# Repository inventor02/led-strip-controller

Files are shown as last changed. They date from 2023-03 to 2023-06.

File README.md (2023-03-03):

# led-strip-controller

The LED Strip Controller is a RP2040 (Pi Pico) based controller for a 12V DC LED strip we had lying around. Instead of
spending £20 on a cheap controller, why not spend much more (and countless hours) on making our own absurdly overengineered
one!?

## Firmware

The firmware, located in `firmware` is WIP.

## Hardware

### PCB

The entire controller is based around one PCB available in the `hardware/board` directory. It is designed using KiCad.

### Box

There is a box that can be 3D printed to fit the PCB and its components well. It is in the `hardware/box` directory, and
was designed using FreeCAD.

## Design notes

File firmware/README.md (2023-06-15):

# led-strip-controller firmware

This is firmware for an RP2040 microcontroller from Raspberry Pi. We use a Pi Pico soldered directly onto the PCB, but theoretically you could use any other RP2040-based board (or even just an RP2040 itself, if you take care of the voltage).

## Resources

- [https://www.techdesign.be/projects/011/011_waves.htm] is a useful page detailing timing requirements for the Samsung IR protocol - Samsung also have an application note which if you're good at looking you can find, and the timings there match too. In the real world the tolerances are much higher anyway.

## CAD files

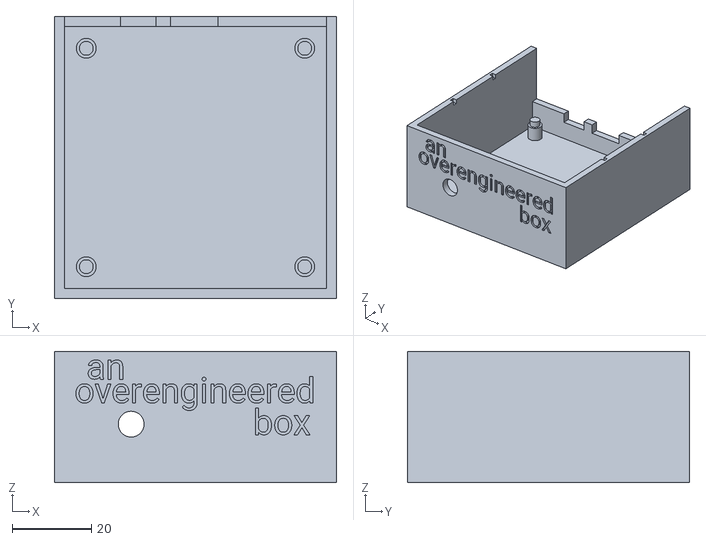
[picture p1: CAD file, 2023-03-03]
hardware/board/release/box/v5_base.stl
71.0 x 71.0 x 33.0

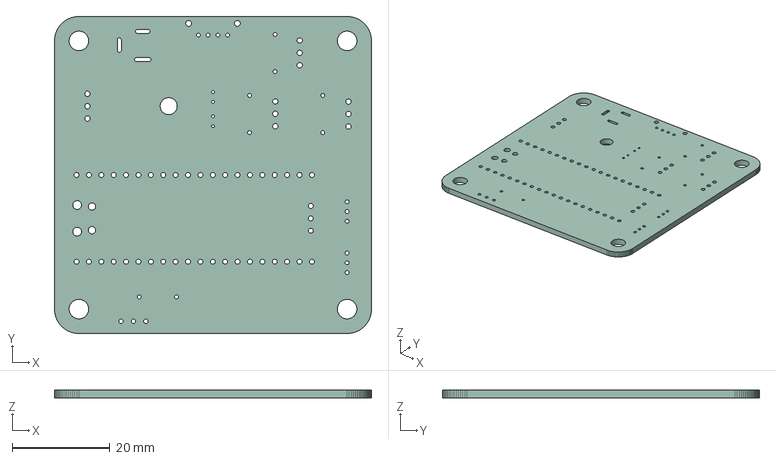
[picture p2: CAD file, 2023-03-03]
hardware/board/release/led_strip_controller.step
65.0 x 65.0 x 1.60 mm

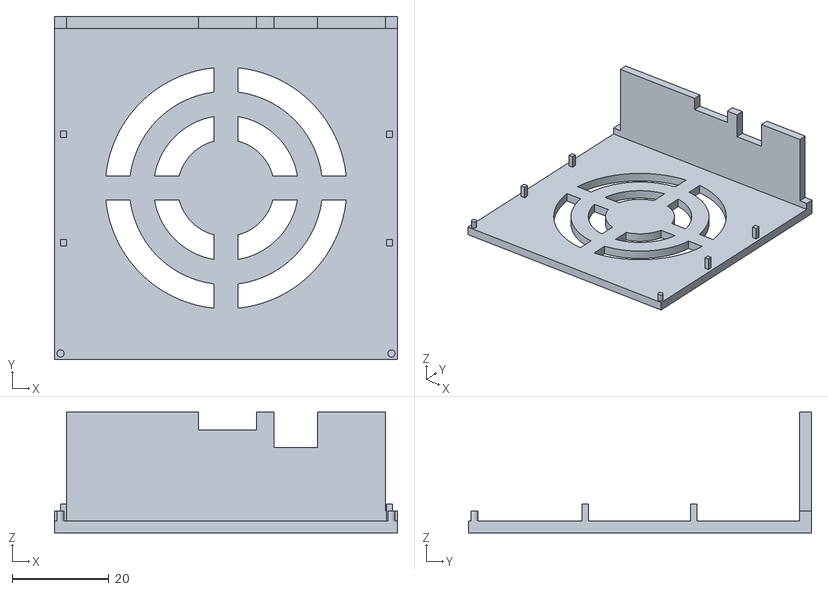
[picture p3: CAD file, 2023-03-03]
hardware/board/release/box/v5_top.stl
71.0 x 71.0 x 25.0

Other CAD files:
hardware/box/boxv5.FCStd

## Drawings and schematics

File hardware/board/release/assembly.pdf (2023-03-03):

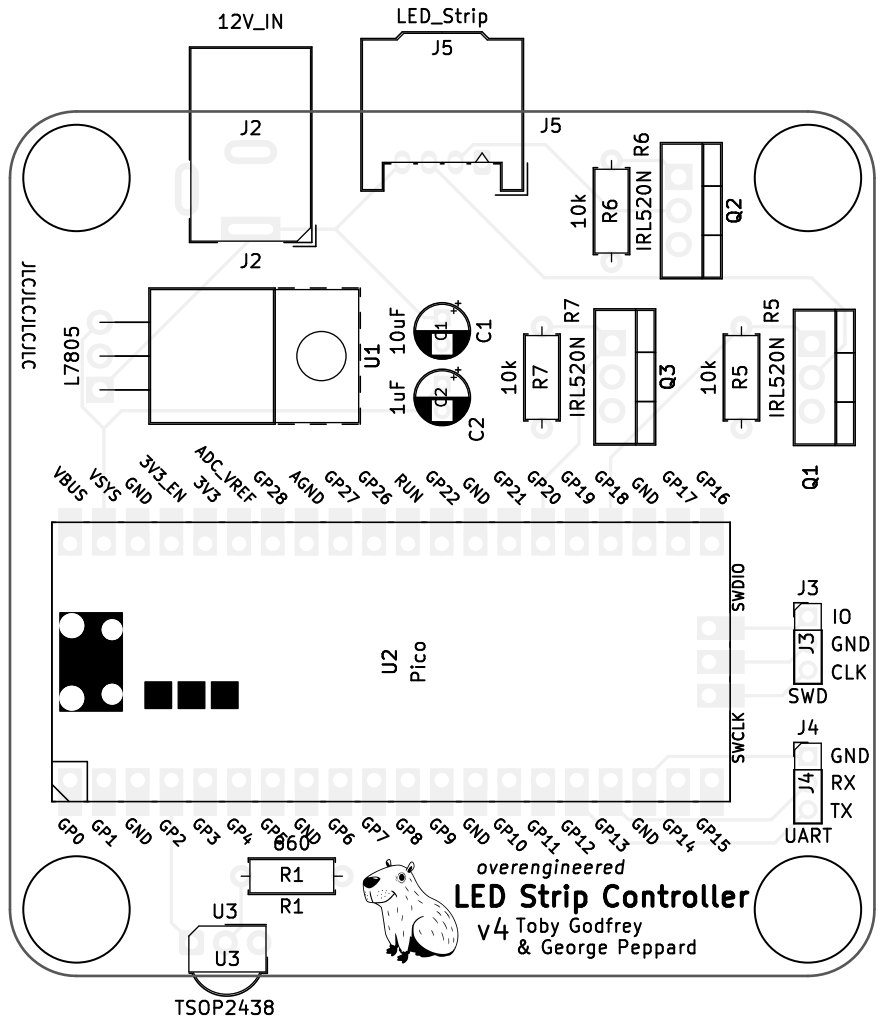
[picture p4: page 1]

Toby Godfrey & George Peppard

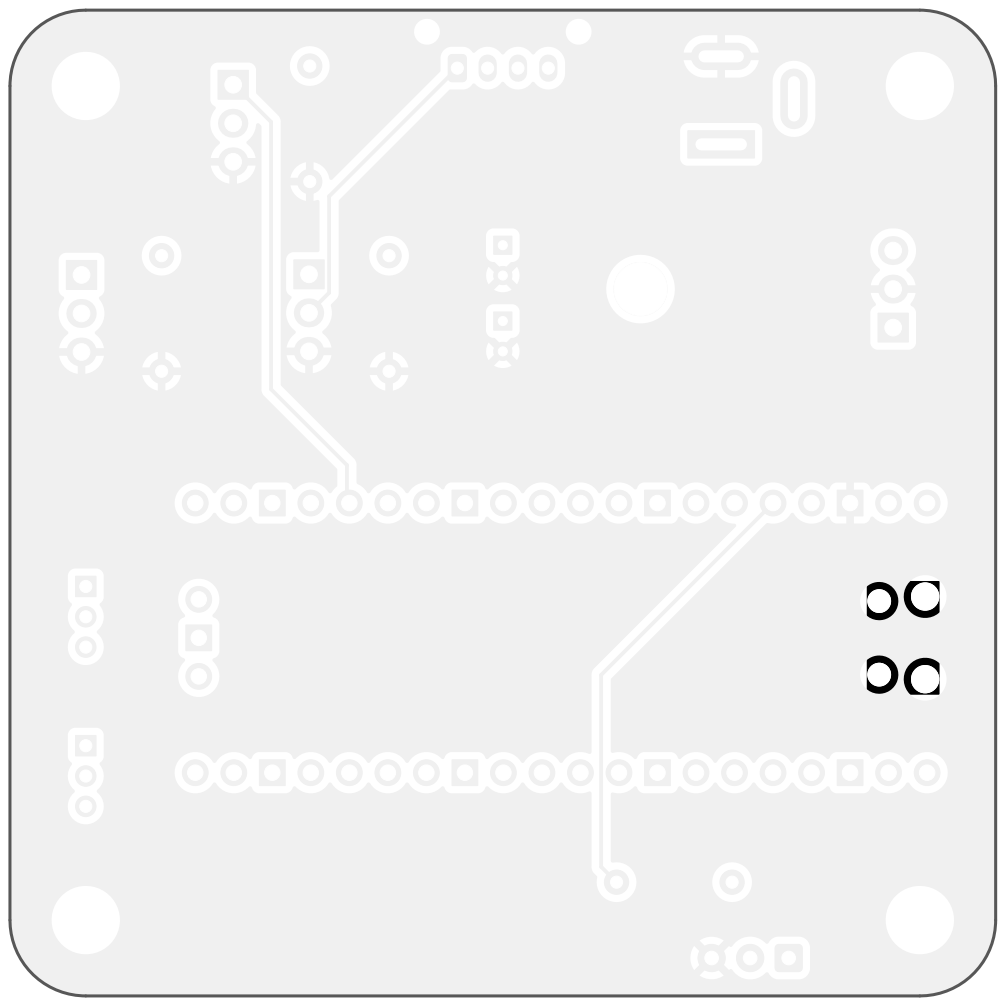
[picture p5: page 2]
D Date: 2023-03-02 KiCad; kicad; 7.0.0-1.fc37 Size: A4; Rev: 4; Id: 1/1 Title: LED Strip Controller File: led_strip_controller.kicad_pcb Sheet: Toby Godfrey & George; Peppard

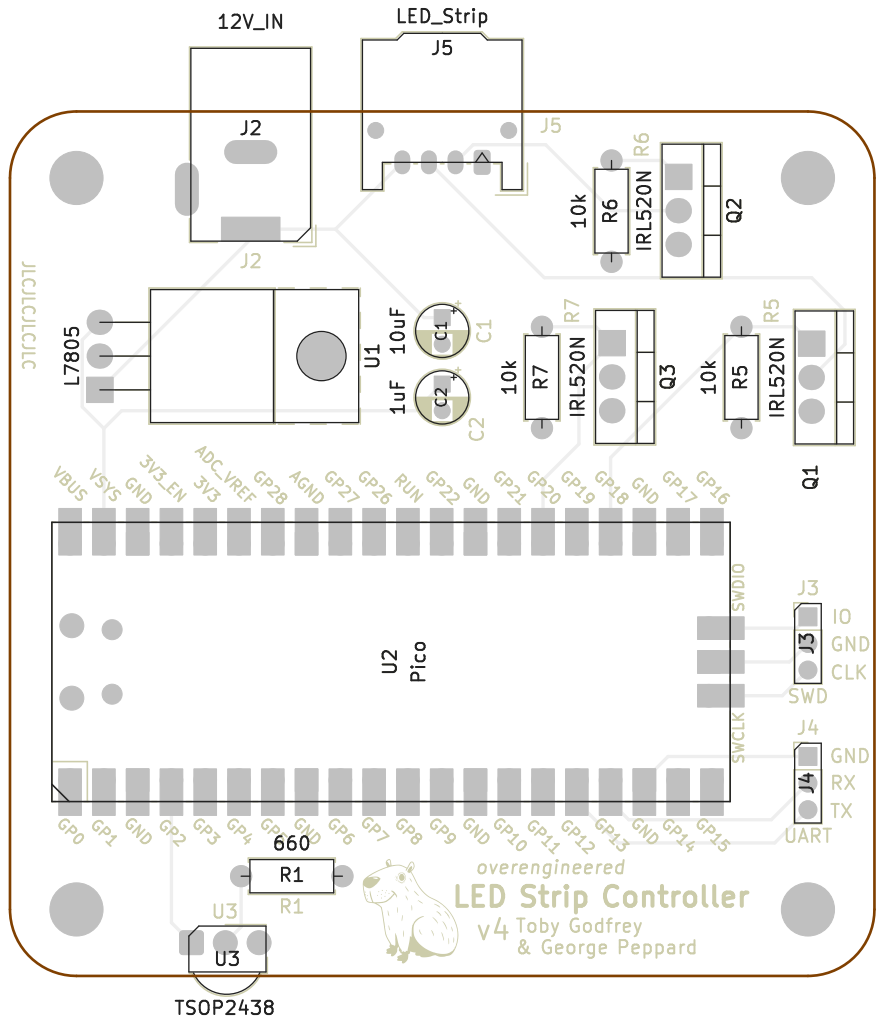
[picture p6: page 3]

Toby Godfrey & George Peppard

Id: 1/1 Title: LED Strip Controller File: led_strip_controller.kicad_pcb Sheet: Toby Godfrey & George Peppard

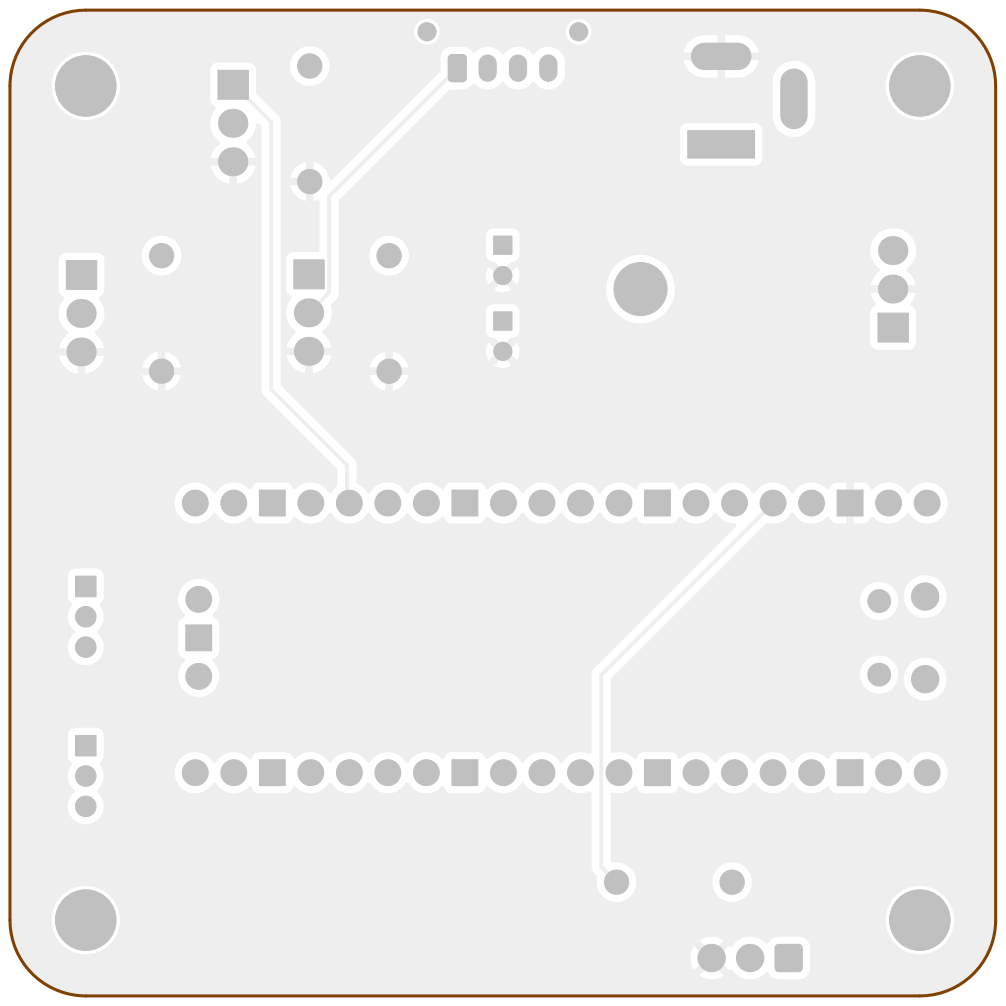
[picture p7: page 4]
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

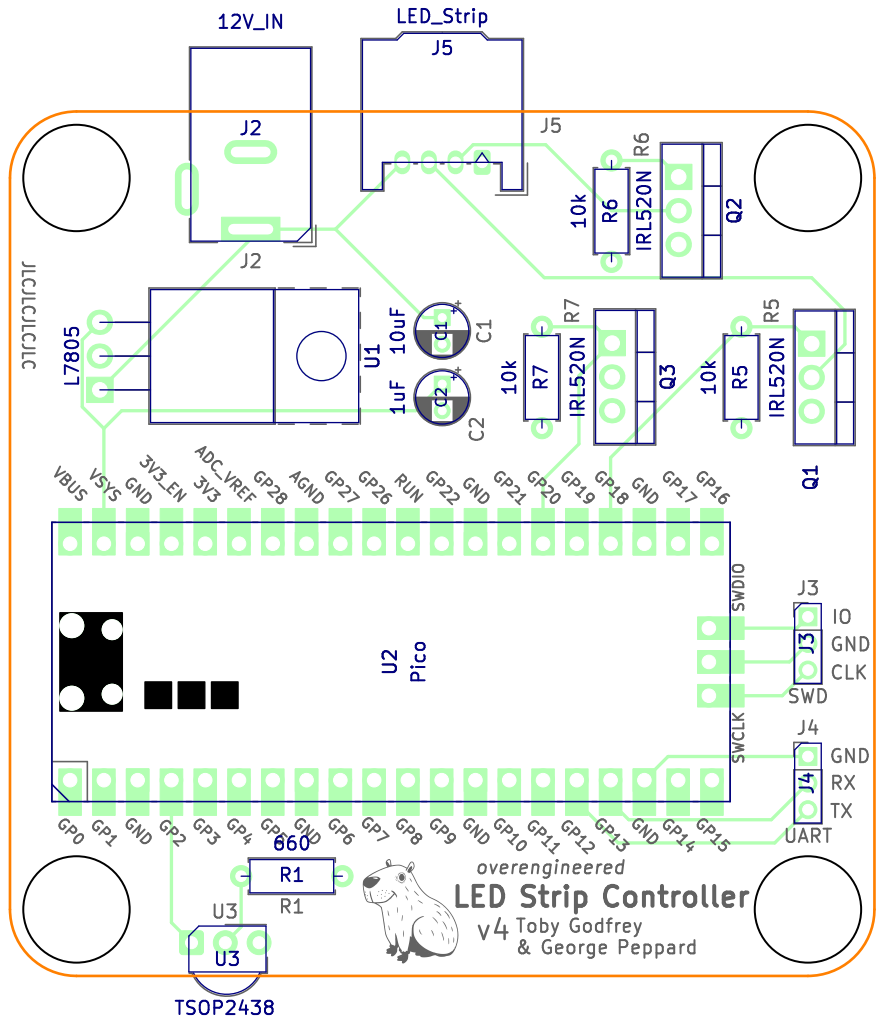
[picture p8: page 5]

Toby Godfrey & George Peppard

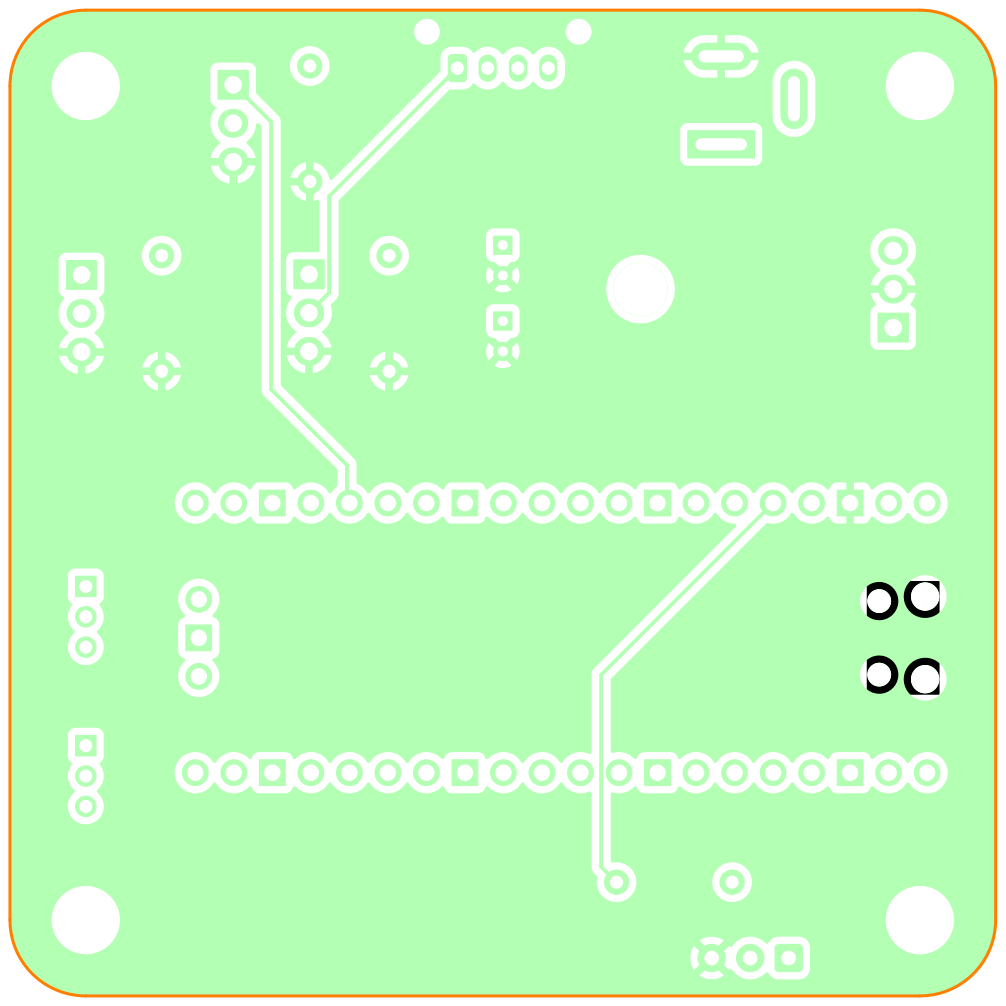
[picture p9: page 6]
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

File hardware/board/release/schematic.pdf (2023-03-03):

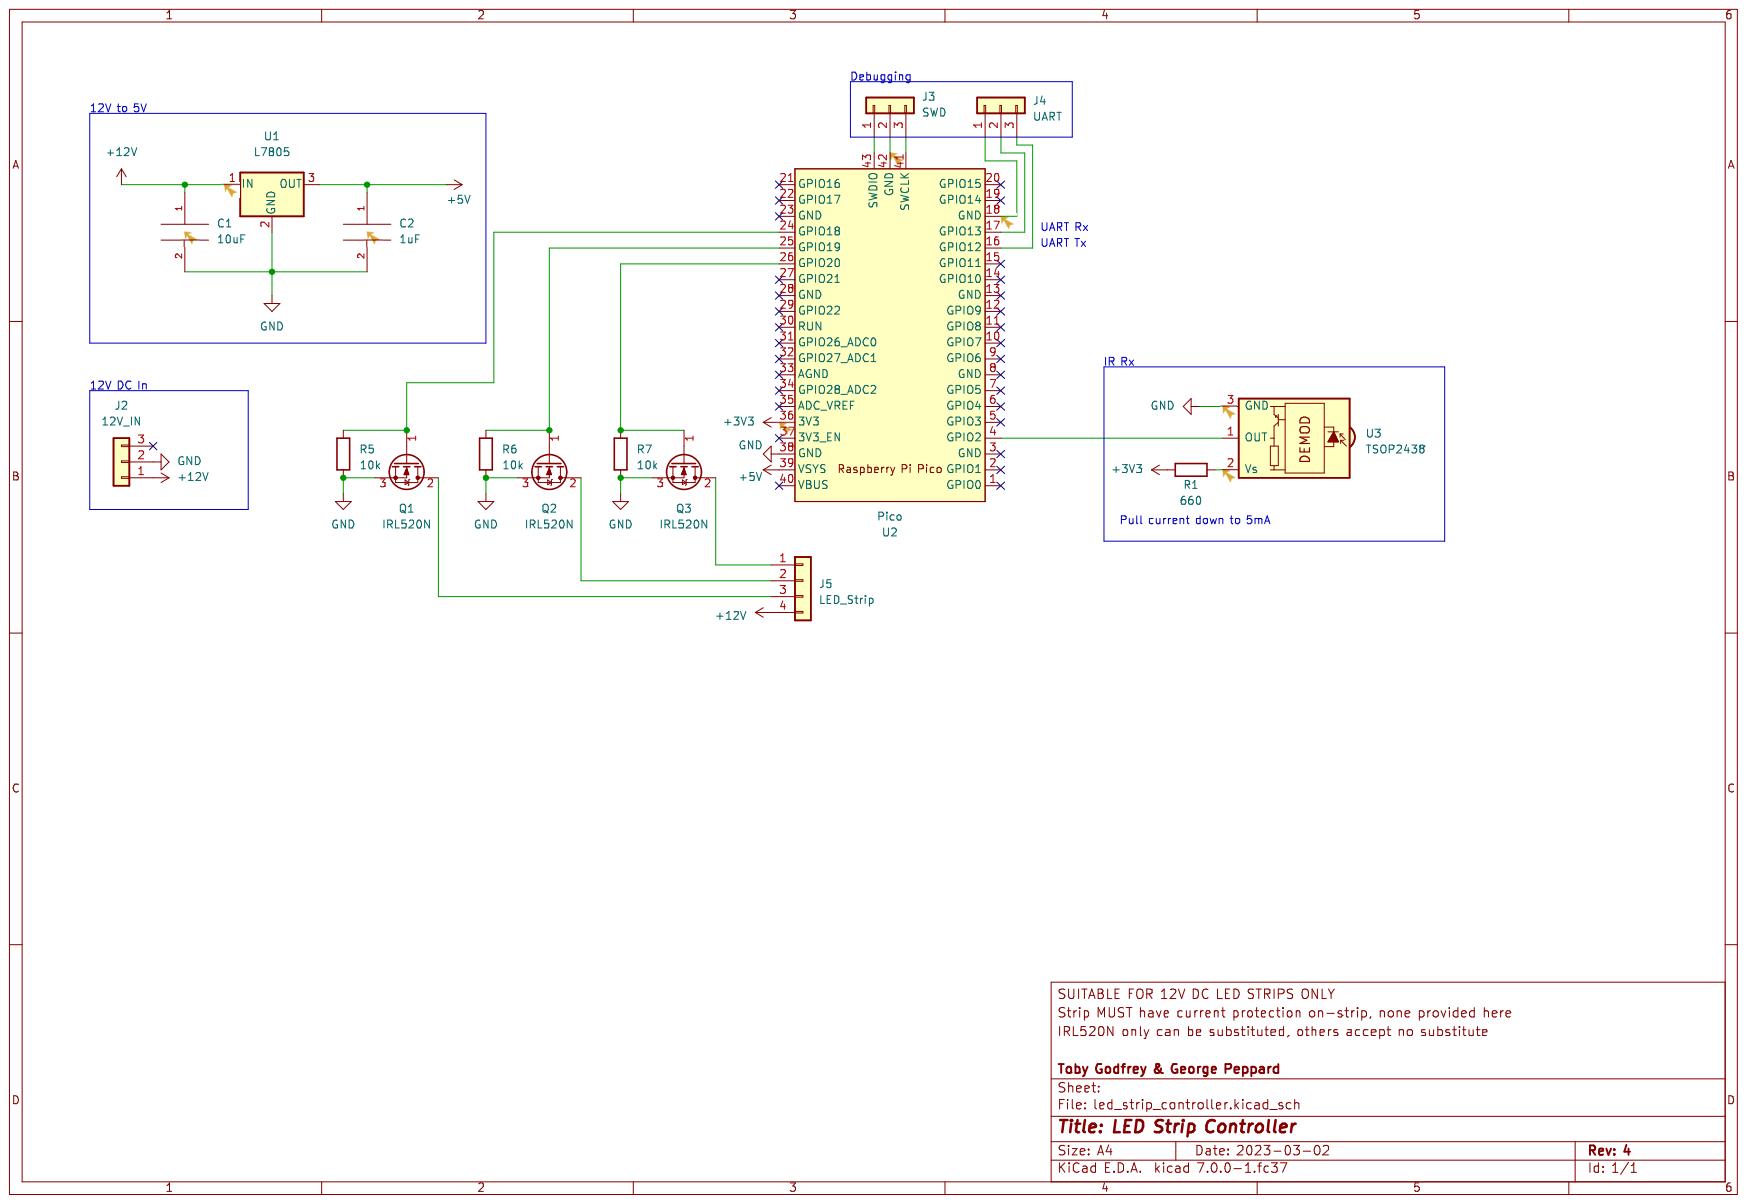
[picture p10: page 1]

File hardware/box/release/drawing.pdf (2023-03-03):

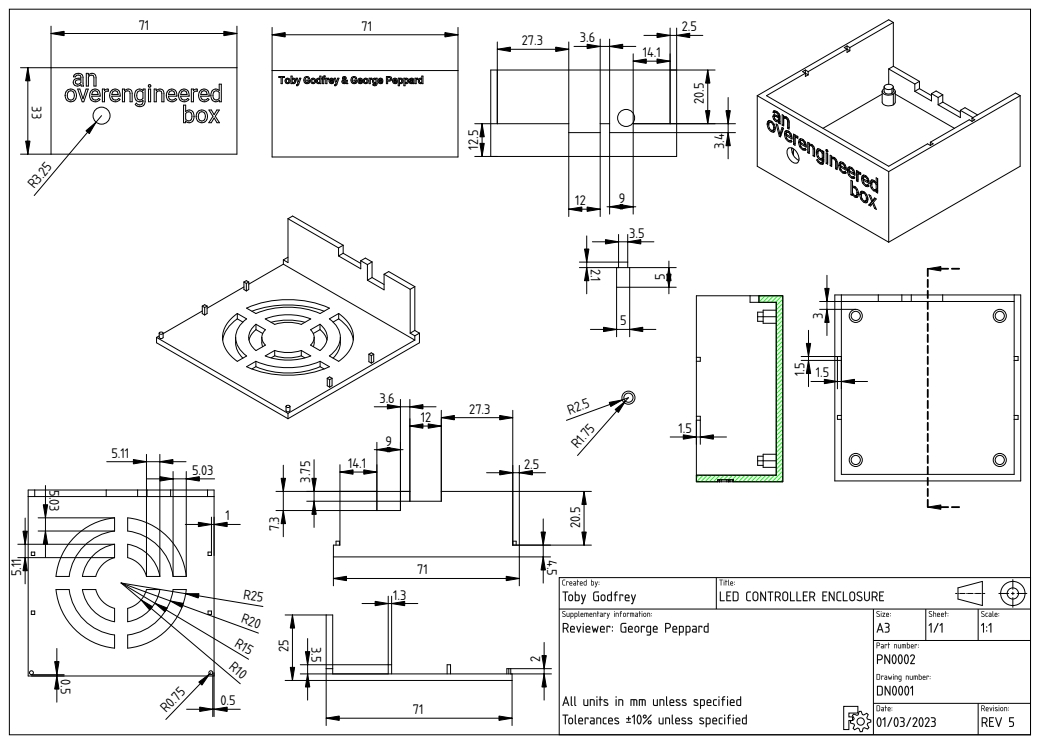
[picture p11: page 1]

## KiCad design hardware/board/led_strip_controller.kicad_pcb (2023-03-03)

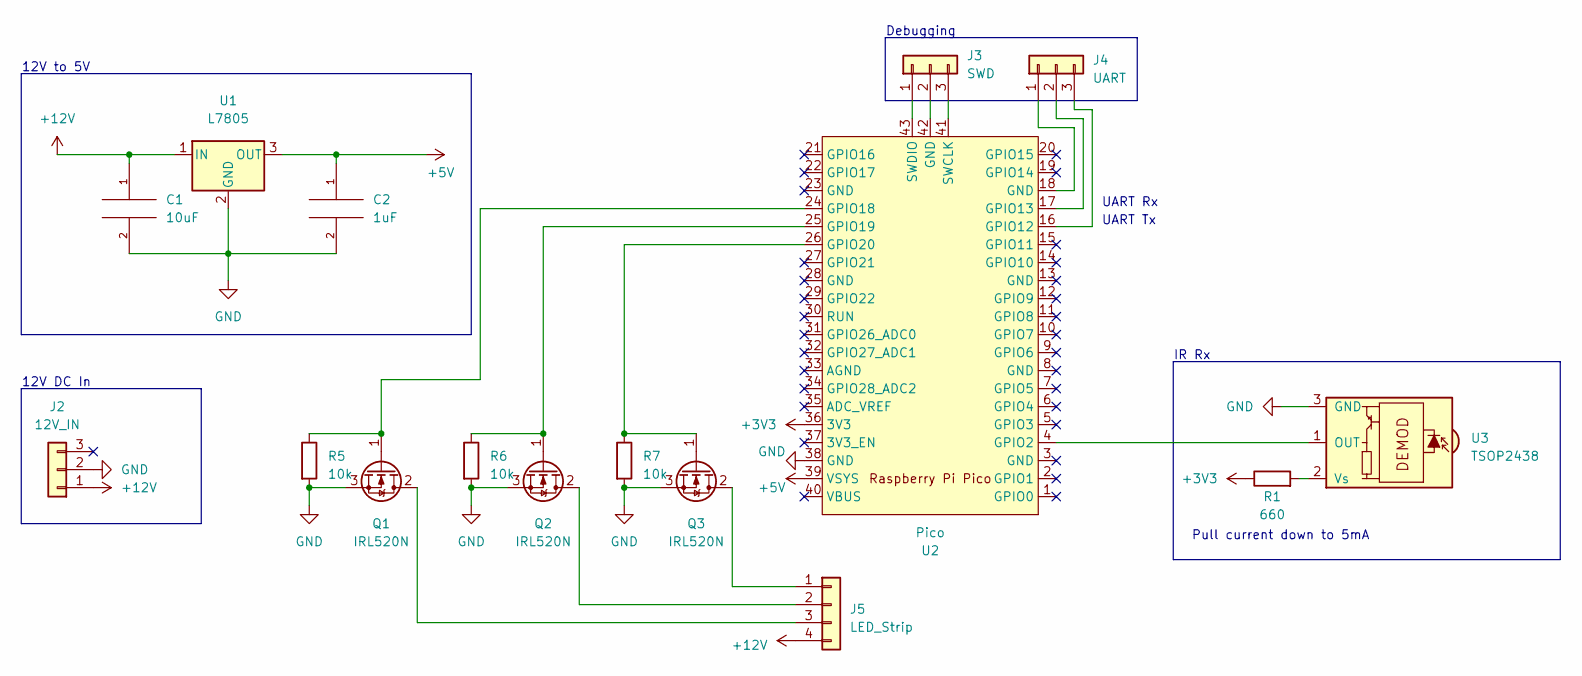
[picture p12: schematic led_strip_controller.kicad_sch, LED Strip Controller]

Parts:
C1: 10uF; CP_Radial_D4.0mm_P2.00mm
C2: 1uF; CP_Radial_D4.0mm_P2.00mm
J2: 12V_IN; BarrelJack_Wuerth_6941xx301002
J3: SWD; PinHeader_1x03_P2.00mm_Vertical
J4: UART; PinHeader_1x03_P2.00mm_Vertical
J5: LED_Strip; Molex_MicroClasp_55935-0410_1x04_P2.00mm_Horizontal
Q1, Q2, Q3: IRL520N; TO-220-3_Vertical
R1: 660; R_Axial_DIN0207_L6.3mm_D2.5mm_P7.62mm_Horizontal
R5, R6, R7: 10k; R_Axial_DIN0207_L6.3mm_D2.5mm_P7.62mm_Horizontal
U1: L7805; TO-220-3_Horizontal_TabUp
U2: Pico; RPi_Pico_SMD_TH
U3: TSOP2438; Vishay_MOLD-3Pin

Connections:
+3V3: R1.1, U2.36 (3V3)
+5V: C2.1, U1.3 (OUT), U2.39 (VSYS)
+12V: C1.1, J2.1, J5.4, U1.1 (IN)
GND: C1.2, C2.2, J2.2, Q1.3 (S), Q2.3 (S), Q3.3 (S), R5.2, R6.2, R7.2, U1.2 (GND), U2.38 (GND), U3.3 (GND)
unnamed: J3.1, U2.43 (SWDIO)
unnamed: J3.2, U2.42 (GND)
unnamed: J3.3, U2.41 (SWCLK)
unnamed: J4.1, U2.18 (GND)
unnamed: J4.2, U2.17 (GPIO13)
unnamed: J4.3, U2.16 (GPIO12)
unnamed: J5.1, Q3.2 (D)
unnamed: J5.2, Q2.2 (D)
unnamed: J5.3, Q1.2 (D)
unnamed: Q1.1 (G), R5.1, U2.24 (GPIO18)
unnamed: Q2.1 (G), R6.1, U2.25 (GPIO19)
unnamed: Q3.1 (G), R7.1, U2.26 (GPIO20)
unnamed: U2.4 (GPIO2), U3.1 (OUT)
unnamed: R1.2, U3.2 (Vs)

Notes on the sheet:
UART Rx
Pull current down to 5mA
Debugging
UART Tx
12V DC In
12V to 5V
IR Rx

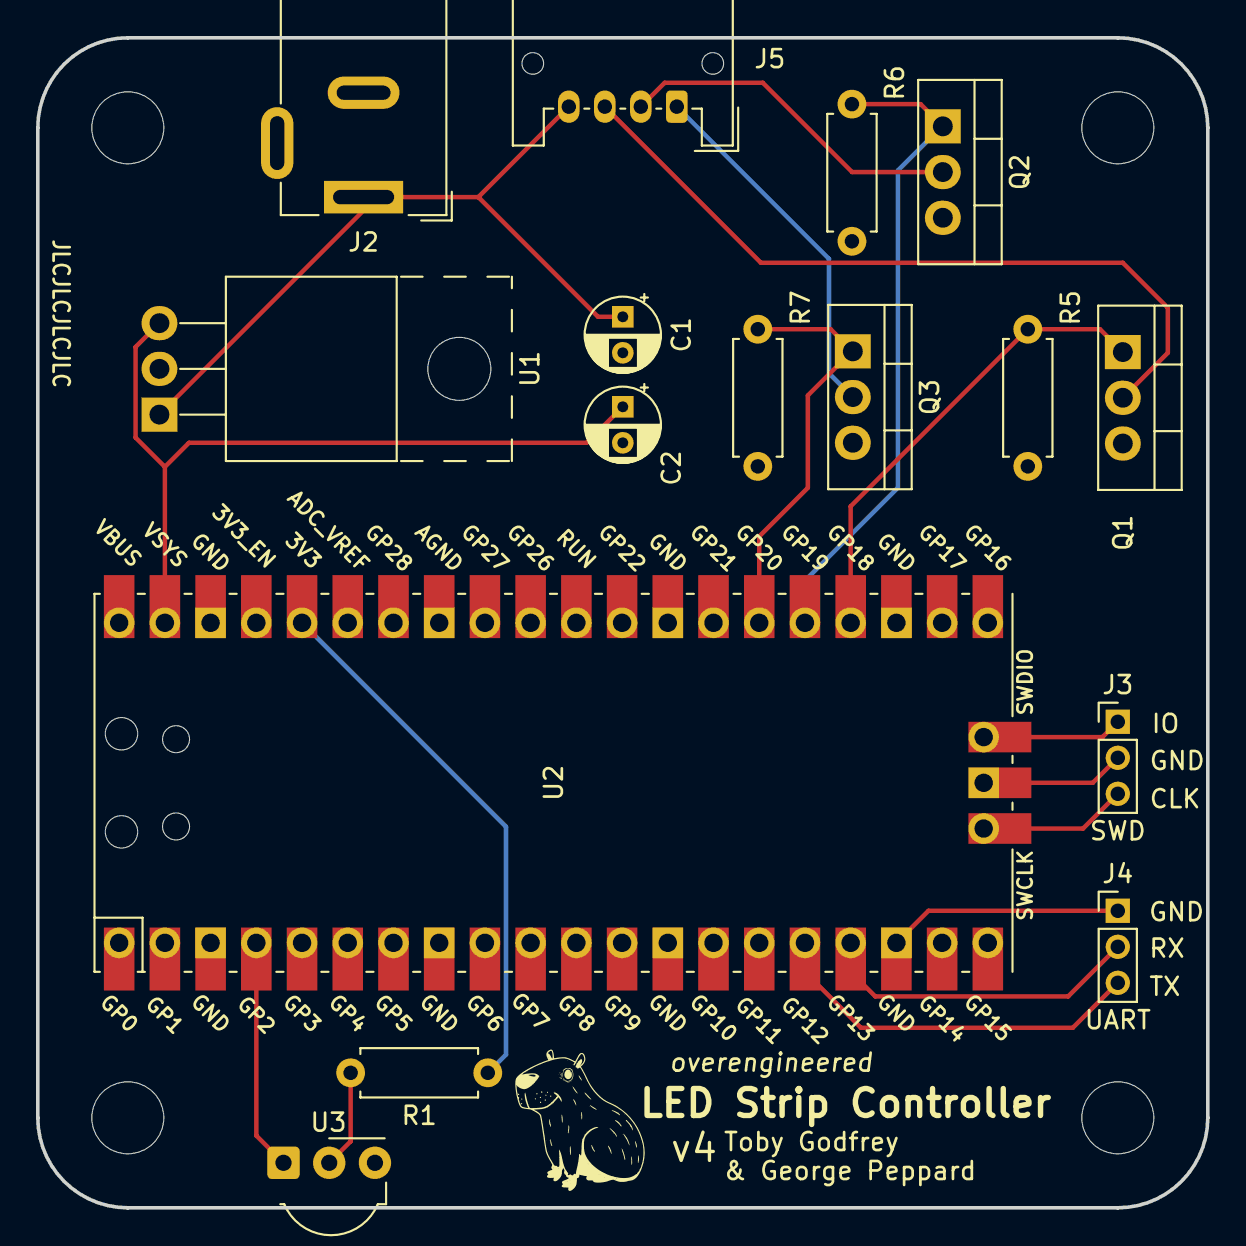
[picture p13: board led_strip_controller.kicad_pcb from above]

Board: 2 copper layers, 65.0 x 65.0 mm, 16 parts (0 on the bottom side), 18 nets.

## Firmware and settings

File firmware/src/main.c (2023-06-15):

#include <stdio.h>
#include <time.h>
#include <math.h>

#include "pico/stdlib.h"
#include "hardware/gpio.h"
#include "hardware/sync.h"
#include "hardware/timer.h"
#include "hardware/pwm.h"
#include "hardware/pio.h"

#include "defs.h"
#include "ir_rx.pio.h"

// % of full power
double red_val = 0;
double green_val = 0;
double blue_val = 0;

bool lights_on = false;

static PIO pio = pio0;
static uint pio_sm;

void self_test() {
  // TODO
}

void set_pwm(double red, double green, double blue) {
  uint red_pwm = floor(red * PWM_WRAP);
  uint green_pwm = floor(green * PWM_WRAP);
  uint blue_pwm = floor(blue * PWM_WRAP);

  pwm_set_gpio_level(PIN_PWM_RED, red_pwm);
  pwm_set_gpio_level(PIN_PWM_GREEN, green_pwm);
  pwm_set_gpio_level(PIN_PWM_BLUE, blue_pwm);
}

void write_light_stored_vals() {}
void write_light_custom_vals(double red, double green, double blue) {}

void button_on_off_toggle() {
  if(!lights_on){
    // Turn on
    lights_on = true;
    // Write the stored values to the lights
    write_light_stored_vals();
  } else {
    lights_on = false;
    // Don't update the values, just write 0 to all of the lights 
    write_light_custom_vals(0, 0, 0);
  }
}

void update_val(double* val) {
  *val += 0.1;
  if(*val > 1) *val -= 1;
}

void ir_isr(uint gpio, uint32_t events) {
  uint32_t state = save_and_disable_interrupts();
  // GPIO_GET 0 - low, !=0 high

  // Check start bit - 4.5ms high, 4.5ms low => 4.5ms low, 4.5ms high
  bool was_low = true;
  bool was_high = true;
  busy_wait_ms(2);
  if (gpio_get(PIN_IR) != 0) was_low = false;
  busy_wait_us(4500);
  // Should switch to high now after ~0.5ms
  // Now 1.5ms into high band
  if (gpio_get(PIN_IR) == 0) was_high = false;

  // Now at ~6.5ms
  busy_wait_us(2000);

  uint8_t bits[32];
  uint32_t code = 0;

  if (was_low && was_high) { // Start bit found
    for (uint8_t i = 0; i < 32; i++) {
      busy_wait_us(560); // Wait until start of second pulse
      // 1.69ms high for 1, 0.56ms high for 0
      
      busy_wait_us(560);
      if (gpio_get(PIN_IR) != 0) {
        code += 2^i;
        busy_wait_us(1130);
        printf("high\n");
      } // Still high
      else continue;
    }
  } else {
    restore_interrupts(0);
    return;
  }


  // Store Data
  switch (code) {
    case POWER_CODE:
      button_on_off_toggle();
      break;
    case RED_CODE:
      update_val(&red_val);
      break;
    case GREEN_CODE:
      update_val(&green_val);
      break;
    case BLUE_CODE:
      update_val(&blue_val);
      break;
    
    default:
      write_light_custom_vals(1, 1, 1);
      break;
  }

  printf("%d\n", code);

  write_light_stored_vals();
  restore_interrupts(0);
}

void init() {
  // setup LED
  gpio_init(PIN_LED);
  gpio_set_dir(PIN_LED, GPIO_OUT);
  gpio_put(PIN_LED, 1);

  // setup UART
  stdio_uart_init_full(uart0, 115200, PIN_UART_TX, PIN_UART_RX);
  printf("Hello; LED Strip Controller v%s\n\n", VERSION);

  // set pins for PWM
  gpio_set_function(PIN_PWM_RED, GPIO_FUNC_PWM);
  gpio_set_function(PIN_PWM_GREEN, GPIO_FUNC_PWM);
  gpio_set_function(PIN_PWM_BLUE, GPIO_FUNC_PWM);

  uint pwm_red_slice = pwm_gpio_to_slice_num(PIN_PWM_RED);
  uint pwm_green_slice = pwm_gpio_to_slice_num(PIN_PWM_GREEN);
  uint pwm_blue_slice = pwm_gpio_to_slice_num(PIN_PWM_BLUE);

  pwm_set_wrap(pwm_red_slice, PWM_WRAP);
  pwm_set_wrap(pwm_green_slice, PWM_WRAP);
  pwm_set_wrap(pwm_blue_slice, PWM_WRAP);

  pwm_set_gpio_level(PIN_PWM_RED, 0);
  pwm_set_gpio_level(PIN_PWM_GREEN, 0);
  pwm_set_gpio_level(PIN_PWM_BLUE, 0);

  pwm_set_enabled(pwm_red_slice, true);
  pwm_set_enabled(pwm_green_slice, true);
  pwm_set_enabled(pwm_blue_slice, true);

  pio_sm = pio_claim_unused_sm(pio, true);
  uint offset = pio_add_program(pio, &ir_rx_program);
  ir_rx_program_init(pio, pio_sm, offset, PIN_IR);

  printf("Initialisation complete\n");
}

int main() {
  init();
  self_test();

  for (;;) {
    uint32_t rx = pio_sm_get_blocking(pio, pio_sm);
    printf("received: %x\n", rx);
  }
}

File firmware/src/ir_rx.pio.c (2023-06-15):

#include "ir_rx.pio.h"

#include "pico/stdlib.h"
#include "hardware/pio.h"
#include "hardware/clocks.h"

void ir_rx_program_init(PIO pio, uint sm, uint offset, uint gpio)
{
    // get the default config for this program
    pio_sm_config config = ir_rx_program_get_default_config(offset);

    // set up our pins
    pio_gpio_init(pio, gpio);
    gpio_pull_up(gpio);
    pio_sm_set_consecutive_pindirs(pio, sm, gpio, 1, false);
    sm_config_set_in_pins(&config, gpio);
    sm_config_set_jmp_pin(&config, gpio);
    
    // join the TX FIFO to the RX FIFO, doubling the length of the RX FIFO
    sm_config_set_fifo_join(&config, PIO_FIFO_JOIN_RX);

    // set the ISR as right to left (as LSB first), autopush after 32 bits
    sm_config_set_in_shift(&config, true, true, 24);

    // calculate how fast we want to run our clock (TSHORT should be 560us)
    float target_clock_hz = ir_rx_TSHORT / 560e-6;

    // calculate the clock divider
    float clkdiv = clock_get_hz(clk_sys) / target_clock_hz;
    sm_config_set_clkdiv(&config, clkdiv);

    // start the PIO
    pio_sm_set_config(pio, sm, &config);
    pio_sm_set_enabled(pio, sm, true);
}

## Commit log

2023-03-11 feat: basic UART out and pin select
2023-03-22 add pwm stuff
2023-06-14 chore: update pico SDK
